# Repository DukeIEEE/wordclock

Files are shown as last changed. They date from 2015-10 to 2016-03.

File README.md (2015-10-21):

Wordclock
=========

Instructables: http://www.instructables.com/id/wordclock/

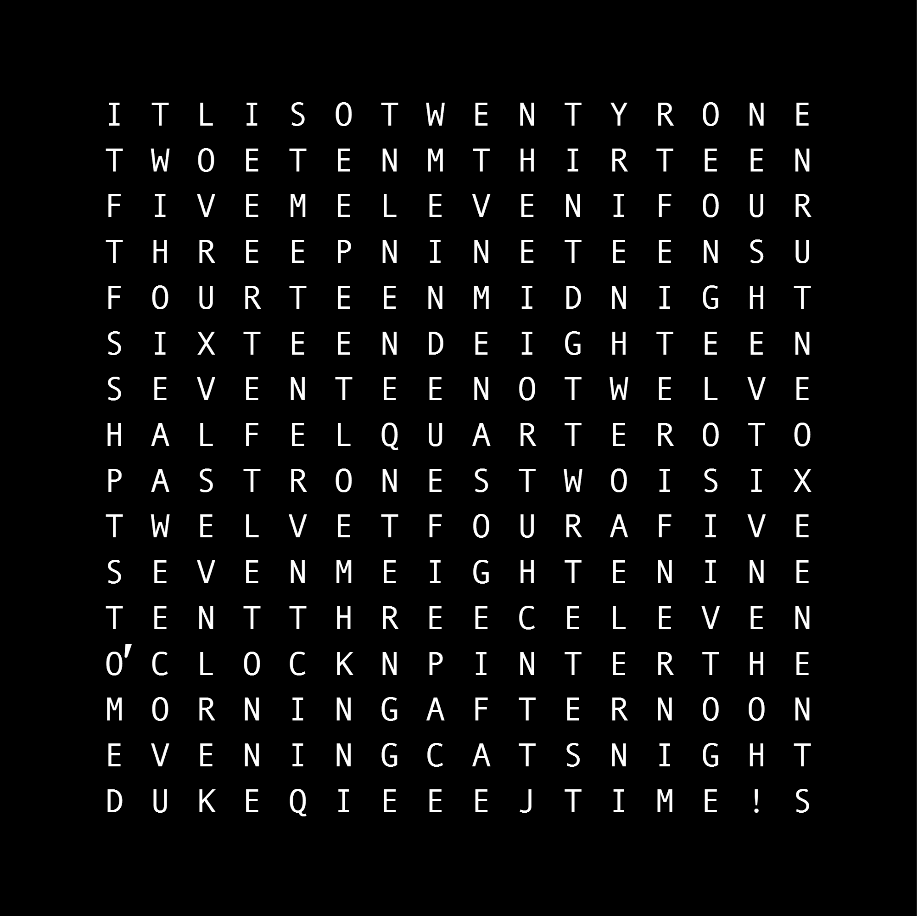
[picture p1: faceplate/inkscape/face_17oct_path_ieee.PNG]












Video on YouTube (http://www.youtube.com/watch?v=86BiDWXyuwA)

<br />This work is licensed under a <a rel="license" href="http://creativecommons.org/licenses/by-nc-sa/4.0/">Creative Commons Attribution-NonCommercial-ShareAlike 4.0 International License</a>.

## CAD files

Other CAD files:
faceplate/face_vector_ieee.dwg

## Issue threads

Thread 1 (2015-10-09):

Edit letter layout to include ELEVEN for hours

qian-wang, 2015-10-09:
Original design missed ELEVEN as used in the hour indicator. We can get rid of the temperature words (in pink) below to add it in. May want to add NOON as well.

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

Closed 2016-04-23.

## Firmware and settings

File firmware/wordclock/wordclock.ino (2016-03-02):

// Wordclock firmware
// ==================
// November 2013 - August 2014
// by Wouter Devinck

// Dependencies:
//  * Arduino libraries                - http://arduino.cc/
//  * Chronodot library (for DS3231)   - https://github.com/Stephanie-Maks/Arduino-Chronodot
//  * LedControl library (for MAX7219) - http://playground.arduino.cc/Main/LedControl

/* Hardware block diagram:

              +-----------------+
              | Real time clock |
              | Maxim DS3231    |
              +--------+--------+
                       |I2C
         +-------------+-------------+
         |                           |   +------------------+
         |                           +---+ 8x8 LED matrix 1 |
  +---+    |                           |   | Maxim MAX7219    |
  |LDR+----+                           |   +---------+--------+
  +---+    |      Microcontroller      |             |
         |      Atmel ATMEGA328      |   +---------+--------+
  +------+ |      (with Arduino        |   | 8x8 LED matrix 2 |
  |Buzzer+-+       bootloader)         |   | Maxim MAX7219    |
  +------+ |                           |   +---------+--------+
         |                           |             |
         |                           |   +---------+--------+
         +-++----++---------++----++-+   | 8x8 LED matrix 3 |
           ||    ||         ||    ||     | Maxim MAX7219    |
    +------++-+  ||  +------++-+  ||     +---------+--------+
    | Azoteq  |  ||  | Azoteq  |  ||               |
    | IQS127D |  ||  | IQS127D |  ||     +---------+--------+
    +---------+  ||  +---------+  ||     | 8x8 LED matrix 4 |
                 ||               ||     | Maxim MAX7219    |
          +------++-+      +------++-+   +------------------+
          | Azoteq  |      | Azoteq  |
          | IQS127D |      | IQS127D |
          +---------+      +---------+

  (created using http://asciiflow.com/) */


// Includes
#include "LedControl.h" // MAX7219 - LED matrix drivers - http://playground.arduino.cc/Main/LedControl
#include "Chronodot.h"  // DS3231  - Real time clock    - https://github.com/Stephanie-Maks/Arduino-Chronodot
#include <Wire.h>
#include <EEPROM.h>

// Pins to capacitive touch chips (touch and presence for each of the Azoteq IQS127D chips in the four corners)
const int pinTRB = 9;   // Touch Right Bottom
const int pinTRT = 3;   // Touch Right Top
const int pinTLT = 4;   // Touch Left Top
const int pinTLB = 10;  // Touch Left Bottom
// The presence pins are connected in hardware, but not used in this firmware.
// Leaving the pin numbers in as comments for future reference.
//const int pinPRB = 5; // Presence Right Bottom
//const int pinPRT = 8; // Presence Right Top
//const int pinPLT = 7; // Presence Left Bottom
//const int pinPLB = 6; // Presence Left Top

// Pins to led drivers
const int pinData = 14; // A0 (used as digital pin)
const int pinLoad = 15; // A1 (used as digital pin)
const int pinClock = 16; // A2 (used as digital pin)

// Other pins (buzzer and light sensor)
const int pinBuzzer = 2;
const int pinLDR = 3; // A3 (used as analog pin)

// Constants
const int noBoards = 4; // number of chained LED drivers

// Settings (will be fetched from EEPROM)
int brightness; // Between 0 and 15

// The led controllers (MAX7219)
LedControl lc = LedControl(pinData, pinClock, pinLoad, noBoards);

// The real time clock chip (DS3231)
Chronodot RTC;

// LED grid
const int bs = 8;
const int bss = 3;
const int boards[2][2] = { {2, 1}, {3, 0} };

// Tasks
const int wait = 10;
const int noTasks = 3;
typedef struct Tasks {
  long unsigned int previous;
  int interval;
  void (*function)();
} Task;
Task tasks[noTasks];

// Serial menu options
boolean mustReadBrightness = false;

// Buffer
boolean prevframe[16][16];

// Words

// Format: { line index, start position index, length }

const int w_it[3] =        { 0,  0,  2 };
const int w_is[3] =        { 0,  3,  2 };
const int w_half[3] =      { 7,  0,  4 };
const int w_to[3] =        { 7,  14, 2 };
const int w_past[3] =      { 8,  0,  4 };
const int w_oclock[3] =    { 12, 0, 6 };
const int w_in[3] =        { 12, 8,  2 };
const int w_the[3] =       { 12, 13,  3 };
const int w_afternoon[3] = { 13, 7,  9 };
const int w_noon[3] =      { 13, 12, 4 }; // part of "afternoon"
const int w_midnight[3] =  { 4,  8,  8 };
const int w_morning[3] =   { 13, 0,  7 };
const int w_at[3] =        { 14, 8,  2 };
const int w_night[3] =     { 14, 11, 5 };
const int w_evening[3] =   { 14, 0,  7 };
const int w_and[3] =       { 14, 8,  3 };
const int w_duke[3] =      {15, 0, 4  };
const int w_ieee[3] =      {15, 5, 4};
const int w_time[3] =      {15, 10, 5};
const int w_el[3] =        { 9,  2,  2 };
const int w_cold[3] =      {15, 0, 4  }; // do we need these?
const int w_cool[3] =      {15, 5, 4}; // do we need these?
const int w_warm[3] =      {15, 10, 5}; // do we need these?
const int w_hot[3] =        { 9,  2,  2 }; // do we need these?


const int w_minutes[20][3] = {
  { 0,  13, 3 }, // one
  { 1,  0,  3 }, // two
  { 3,  0,  5 }, // three
  { 2,  12, 4 }, // four
  { 2,  0,  4 }, // five
  { 5,  0,  3 }, // six
  { 6,  0,  5 }, // seven
  { 5,  8,  5 }, // eight
  { 3,  6,  4 }, // nine
  { 1,  4,  3 }, // ten
  { 2,  5,  6 }, // eleven
  { 6,  10, 6 }, // twelve
  { 1,  8,  8 }, // thirteen
  { 4,  0,  8 }, // fourteen
  { 7,  6,  7 }, // quarter
  { 5,  0,  7 }, // sixteen
  { 6,  0,  9 }, // seventeen
  { 5,  8,  8 }, // eighteen
  { 3,  6,  8 }, // nineteen
  { 0,  6,  6 }  // twenty
};

const int w_hours[12][3] = {
  { 8,  5,  3 }, // one
  { 8,  9,  3 }, // two
  { 11, 4,  5 }, // three
  { 9,  7,  4 }, // four
  { 9,  12, 4 }, // five
  { 8,  13, 3 }, // six
  { 10, 0,  5 }, // seven
  { 10, 6,  5 }, // eight
  { 10, 12, 4 }, // nine
  { 11, 0,  3 }, // ten
  { 11, 10, 6 }, // eleven
  { 9,  0,  6 }  // twelve
};

// Touch
boolean tlt;
boolean trt;
boolean tlb;
boolean trb;

void setup() {

  // Debug info
  Serial.begin(9600);
  Serial.println("[INFO] Wordclock is booting...");

  // Read settings from EEPROM
  Serial.println("[INFO] 1. Read settings");
  brightness = EEPROM.read(0);

  // Initiate the LED drivers
  Serial.println("[INFO] 2. LED drivers");
  for (int i = 0; i < noBoards; ++i) {
    lc.shutdown(i, false);
    lc.clearDisplay(i);
  }
  setBrightness(brightness);

  // Initiate the Real Time Clock
  Serial.println("[INFO] 3. Real time clock");
  Wire.begin();
  RTC.begin();
  //if (! RTC.isrunning()) {
  //  Serial.println("[WARNING] RTC is NOT running!");
  //  RTC.adjust(DateTime(__DATE__, __TIME__));
  //}

  // Initiate the capacitive touch inputs
  Serial.println("[INFO] 4. Capacitive touch");
  pinMode(pinTRB, INPUT);
  pinMode(pinTRT, INPUT);
  pinMode(pinTLT, INPUT);
  pinMode(pinTLB, INPUT);
  //pinMode(pinPRB, INPUT);
  //pinMode(pinPRT, INPUT);
  //pinMode(pinPLT, INPUT);
  //pinMode(pinPLB, INPUT);

  // Tasks
  Serial.println("[INFO] 5. Tasks");
  loadTasks();

  // Debug info
  Serial.println("[INFO] Wordclock done booting. Hellooooo!");
  printMenu();

}

void loadTasks() {

  // Listen for input on the serial interface
  tasks[0].previous = 0;
  tasks[0].interval = 100;
  tasks[0].function = serialMenu;

  // Show time
  tasks[1].previous = 0;
  tasks[1].interval = 1000;
  tasks[1].function = showTime;

  // Read the touch inputs
  tasks[2].previous = 0;
  tasks[2].interval = 100;
  tasks[2].function = readTouch;

}

void loop() {
  unsigned long time = millis();
  for (int i = 0; i < noTasks; i++) {
    Task task = tasks[i];
    if (time - task.previous > task.interval) {
      tasks[i].previous = time;
      task.function();
    }
  }
  delay(wait);
}

void serialMenu() {
  if (Serial.available() > 0) {
    if (mustReadBrightness) {
      int val = Serial.parseInt();
      if (val < 0 || val > 15) {
        Serial.println("[ERROR] Brightness must be between 0 and 15");
      } else {
        Serial.print("Brightness set to ");
        Serial.println(val, DEC);
        setBrightness(val);
        brightness = val;
        EEPROM.write(0, val);
      }
      mustReadBrightness = false;
      printMenu();
    } else {
      int in = Serial.read();
      if (in == 49) {
        Serial.println("You entered [1]");
        Serial.println("  Enter brightness (0-15)");
        mustReadBrightness = true;
      } else if (in == 50) {
        Serial.println("You entered [2]");
        Serial.print("  Brightness: ");
        Serial.println(brightness, DEC);
        printMenu();
      } else {
        Serial.println("[ERROR] Whut?");
        printMenu();
      }
    }
  }
}

void showTime() {

  // Get the time
  DateTime now = RTC.now();
  int h = now.hour();
  int h2 = h;
  int m = now.minute();
  int t = now.tempC();

  // DEBUG
  /*Serial.print("[DEBUG] ");
    Serial.print(h, DEC);
    Serial.print(':');
    Serial.println(m, DEC);*/

  // The frame
  boolean frame[16][16];
  for (int r = 0; r < 16; r++) {
    for (int c = 0; c < 16; c++) {
      frame[r][c] = false;
    }
  }

  // Show "IT IS"
  addWordToFrame(w_it, frame);
  addWordToFrame(w_is, frame);

  // Minutes
  if (m == 0) {

    if (h == 0) {
      addWordToFrame(w_midnight, frame);
    } else if (h == 12) {
      addWordToFrame(w_noon, frame);
    } else {
      addWordToFrame(w_oclock, frame);
    }

  } else {

    if (m <= 20) {
      addWordToFrame(w_minutes[m - 1], frame);
    } else if (m < 30) {
      addWordToFrame(w_minutes[19], frame); // twenty
      addWordToFrame(w_minutes[m - 21], frame);
    } else if (m == 30) {
      addWordToFrame(w_half, frame);
    } else if (m < 40) {
      addWordToFrame(w_minutes[19], frame); // twenty
      addWordToFrame(w_minutes[60 - m - 21], frame);
    } else {
      addWordToFrame(w_minutes[60 - m - 1], frame);
    }

    if (m <= 30) {
      addWordToFrame(w_past, frame);
    } else {
      addWordToFrame(w_to, frame);
      ++h2;
    }

  }

  if (!(m == 0 && (h == 0 || h == 12))) {

    // Hours
    if (h2 == 0) {
      addWordToFrame(w_hours[11], frame);
    } else if (h2 <= 12) {
      addWordToFrame(w_hours[h2 - 1], frame);
    } else {
      addWordToFrame(w_hours[h2 - 13], frame);
    }
    if (h2 == 11 || h2 == 23) {
      addWordToFrame(w_el, frame);
    }

    // Time of day
    if (h < 6) {
      addWordToFrame(w_at, frame);
      addWordToFrame(w_night, frame);
    } else if (h < 12) {
      addWordToFrame(w_in, frame);
      addWordToFrame(w_the, frame);
      addWordToFrame(w_morning, frame);
    } else if (h < 18) {
      addWordToFrame(w_in, frame);
      addWordToFrame(w_the, frame);
      addWordToFrame(w_afternoon, frame);
    } else {
      addWordToFrame(w_at, frame);
      addWordToFrame(w_night, frame);
    }
  }

  // Duke IEEE Time! (2 PM to 5 PM)
  int weekday = now.dayOfWeek();

  if (weekday = 6 && 14 < h && h < 17) {
    addWordToFrame(w_duke, frame);
    addWordToFrame(w_ieee, frame);
    addWordToFrame(w_time, frame);
  }

  // Temperature
  addWordToFrame(w_and, frame);
  if (t <= 16) {
    addWordToFrame(w_cold, frame);
  } else if (t <= 20) {
    addWordToFrame(w_cool, frame);
  } else if (t <= 30) {
    addWordToFrame(w_warm, frame);
  } else {
    addWordToFrame(w_hot, frame);
  }

  // Update display
  updateDisplay(prevframe, frame);

  // Copy current frame to buffer
  for (int r = 0; r < 16; r++) {
    for (int c = 0; c < 16; c++) {
      prevframe[r][c] = frame[r][c];
    }
  }

}

void readTouch() {
  boolean lt = debounce(digitalRead(pinTLT) == LOW, &tlt);
  boolean rt = debounce(digitalRead(pinTRT) == LOW, &trt);
  boolean lb = debounce(digitalRead(pinTLB) == LOW, &tlb);
  boolean rb = debounce(digitalRead(pinTRB) == LOW, &trb);
  if (lt || rt || lb || rb) {
    tone(pinBuzzer, 500, 100);
  }
}

boolean debounce(boolean value, boolean* store) {
  if (value) {
    if (*store) {
      value = false;
    } else {
      *store = true;
    }
  } else {
    *store = false;
  }
  return value;
}

void setAllLeds(boolean on) {
  for (int i = 0; i < noBoards; ++i) {
    for (int r = 0; r < 8; ++r) {
      lc.setRow(i, r, B11111111);
    }
  }
}

void setLed(int row, int col, boolean on) {
  int t = row >> bss;
  int l = col >> bss;
  int board = boards[t][l];
  int r = row % bs;
  int c = col % bs;
  if (t == 0) {
    if (l == 0) {
      r = bs - 1 - r;
      c = (c + 1) % bs;
    } else {
      int r1 = r;
      r = c;
      c = (r1 + 1) % bs;
    }
  } else {
    if (l == 0) {
      int r1 = r;
      r = bs - 1 - c;
      c = (bs - r1) % bs;
    } else {
      c = (bs - c) % bs;
    }
  }
  lc.setLed(board, r, c, on);
}

void updateDisplay(boolean previousframe[16][16], boolean frame[16][16]) {
  for (int r = 0; r < 16; ++r) {
    for (int c = 0; c < 16; ++c) {
      if (prevframe[r][c] && !frame[r][c]) {
        setLed(r, c, false);
      } else if (!prevframe[r][c] && frame[r][c]) {
        setLed(r, c, true);
      }
    }
  }
}

void addWordToFrame(const int theword[3], boolean frame[16][16]) {
  for (int i = 0; i < theword[2]; ++i) {
    frame[theword[0]][theword[1] + i] = true;
  }
}

void setBrightness(int value) {
  for (int i = 0; i < noBoards; ++i) {
    lc.setIntensity(i, value);
  }
}

void printMenu() {
  Serial.println("");
  Serial.println("Menu");
  Serial.println("----");
  Serial.println("  1. Set brightness");
  Serial.println("  2. Read brightness");
  Serial.println("");
}

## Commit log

2015-10-21 Went ahead and changed all the absolute IMG links on the README to relative links within our own repo.
    Just in case the original repo gets deleted for whatever reason.
2016-03-02 Moved wordclock.ino to wordclock folder to open in Arduino
2016-04-23 Added resized ai file of IEEE faceplate design
    [face_vector_ieee.dwg]
2016-04-29 Resized coverage area smaller
    [face_vector_ieee.dwg]
